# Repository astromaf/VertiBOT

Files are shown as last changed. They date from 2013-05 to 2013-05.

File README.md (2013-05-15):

VertiBOT
========

VertiBOT is an educational project to investigate and understand sensor fusion using kalman and complementary filter algorithm and PID control in an unstable system.

VertiBOT is an inverted pendulum platform that remains balanced by means of two tiny motors, located in the bottom of the structure. The battery is attached in the top of the main body, while the electronics board is located near the rotation axis.
The feedback signal is provided by an IMU 6Dof composed by an accelerometer and a gyro. One ATmega 328 microcontroller execute the main loop every 10 milliseconds. A wireless communication over bluetooth is used to tune and check the signal response in a Graphical User Interface software.

Code,parts, video, and diagrams available in: http://madebyfrutos.wordpress.com/2013/05/02/vertibot/
 
Made(by)Frutos http://madebyfrutos.wordpress.com/
  Ocero El Bierzo, Mayo'13

Based on:
- VARESANO's Free IMU library. The hard work is done. Fabio, We won't forget you! 
  http://www.varesano.net/projects/hardware/FreeIMU
- Brett Beauregard. Introducing the Pid.Good PID library and good guide http://goo.gl/QKANE
- Patrick Olsson.X-firm System Projects. Best, Balancing guide. http://www.x-firm.com/
- Jason Dorweiler http://www.jddorweiler.appspot.com/electronics.html
- Much of the code is adapted from http://www.arduino.cc/cgi-bin/yabb2/YaBB.pl?num=1284738418/all
  and http://www.kerrywong.com/2012/03/08/a-self-balancing-robot-i
- Bildr 6Dof IMu notes and library.http://bildr.org/2012/03/stable-orientation-digital-imu-6dof-arduino/
- C. J.Fisher. Using and accelerometer for inclination sensing. Analog Device. AN-1057
- Shane Colton. A Simple solution for Balance Filter. MIT. June 2007
- J.A. Shaw. PID Algorithm & Tuning Methods. Rochester,NY.
     
External specific libraries must be used with this code. All of them are open source and can be found easily in its original repositories.
Thank for the good job done with this libraries. :)
- Free IMU: http://www.varesano.net/projects/hardware/FreeIMU
- Pololu serial-Qik (motor diver): https://github.com/pololu/qik-arduino
- PID library: http://playground.arduino.cc/Code/PIDLibrary

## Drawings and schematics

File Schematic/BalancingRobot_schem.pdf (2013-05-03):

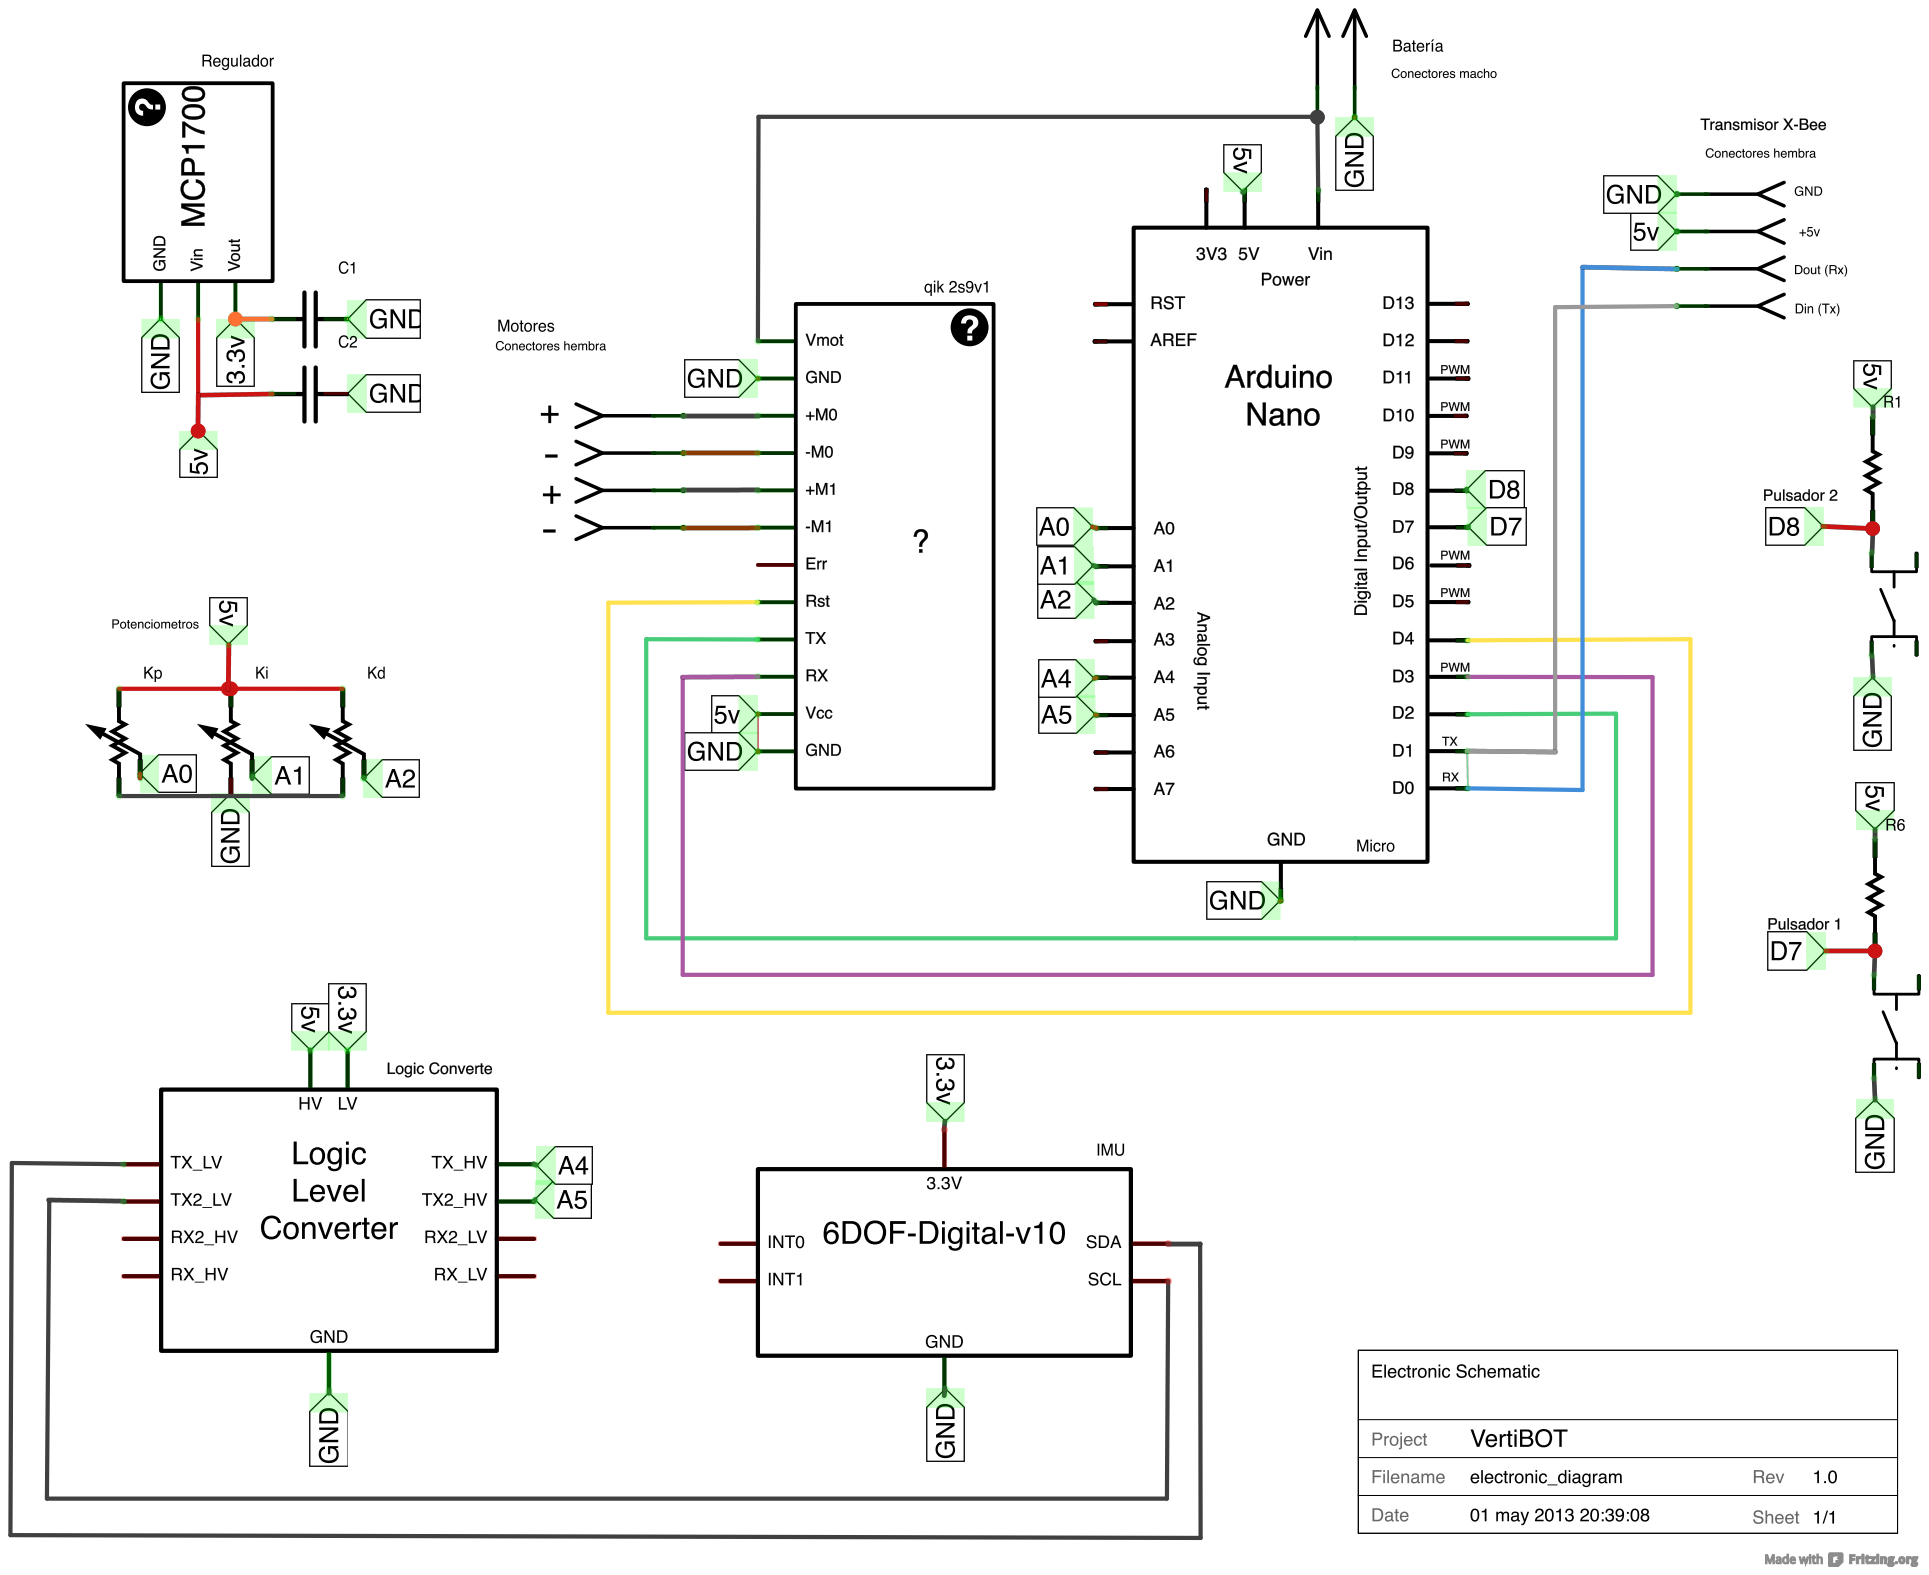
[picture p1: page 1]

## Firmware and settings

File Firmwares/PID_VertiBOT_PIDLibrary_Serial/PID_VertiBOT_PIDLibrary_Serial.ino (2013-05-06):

    /********************************************************
     // Based on:
     // VARESANO's Free IMU library. The hard work is done. Fabio, We won't forget you! http://www.varesano.net/projects/hardware/FreeIMU
     // Brett Beauregard. Introducing the Pid.Good PID library and good guide http://goo.gl/QKANE
     // Patrick Olsson.X-firm System Projects. Best, Balancing guide. http://www.x-firm.com/
     // Jason Dorweiler http://www.jddorweiler.appspot.com/electronics.html
     // Much of the code is adapted from http://www.arduino.cc/cgi-bin/yabb2/YaBB.pl?num=1284738418/all
     // and http://www.kerrywong.com/2012/03/08/a-self-balancing-robot-i
     // Bildr 6Dof IMu notes and library.http://bildr.org/2012/03/stable-orientation-digital-imu-6dof-arduino/
     // C. J.Fisher. Using and accelerometer for inclination sensing. Analog Device. AN-1057
     // Shane Colton. A Simple solution for Balance Filter. MIT. June 2007
     // J.A. Shaw. PID Algorithm & Tuning Methods. Rochester,NY.
     
     // Code,parts, video, and diagrams available in: http://madebyfrutos.wordpress.com/2013/05/02/vertibot/
 
     // Made(by)Frutos http://madebyfrutos.wordpress.com/
     // Ocero El Bierzo, Mayo'13
     
     ********************************************************/
#include <PID_v1.h>

#include <SoftwareSerial.h>
#include <PololuQik.h>

#include <FreeSixIMU.h>
#include <FIMU_ADXL345.h>
#include <FIMU_ITG3200.h>
#include <Wire.h>

//Define Variables we'll be connecting to
double Setpoint, Input, Output;

//Define the aggressive and conservative Tuning Parameters
double aggKp=66, aggKi=4, aggKd=4;
double consKp=1, consKi=0.05, consKd=0.5;

//Specify the links and initial tuning parameters
PID myPID(&Input, &Output, &Setpoint, consKp, consKi, consKd, DIRECT);

unsigned long serialTime=0; //this will help us know when to talk with processing
PololuQik2s9v1 qik(2, 3, 4);

float angles[3]; // yaw pitch roll

// Set the FreeSixIMU object
FreeSixIMU sixDOF = FreeSixIMU();
int a= 1;
int buttonState = 0;

void setup()
{
   Serial.begin(9600);
  pinMode(7, INPUT); 
  pinMode(13, OUTPUT); 
  Setpoint =89;
  qik.init();
  myPID.SetOutputLimits(-127, 127); //[-127, 127]//tell the PID to range between motor PWM response
  myPID.SetSampleTime(10);  // Ensure that the PID is called at regular interval  
  //turn the PID on
  myPID.SetMode(MANUAL);
  Wire.begin();
  
  delay(5);
  sixDOF.init(); //begin the IMU
 
}

void loop()
{
  //Input = analogRead(A0); //read angle[2]
  sensor();
 /*Change the tuning parameters: use Conservative Tuning Parameters when we're near
  setpoint and more agressive Tuning Parameters when we're farther away*/ 
   double gap = abs(Setpoint-Input); //distance away from setpoint
    if(gap<10)
    {  //we're close to setpoint, use conservative tuning parameters
      myPID.SetTunings(consKp, consKi, consKd);
    }
    else
    {
       //we're far from setpoint, use aggressive tuning parameters
       myPID.SetTunings(aggKp, aggKi, aggKd);
    }
   
  myPID.Compute();
  motores();
 // analogWrite(5,Output); //write the motor response
//Serial.println(Output);
  //send-receive with processing if it's time
  if(millis()>serialTime)
  { boton();
    ajuste();
    SerialReceive();
    SerialSend();
    serialTime+=500;
  }
  
} //END LOOP

void motores(){
  qik.setSpeeds(-Output,-Output);
  //delay(5);
}

double sensor(){
sixDOF.getEuler(angles);
Input=abs(angles[2]);

//Serial.print(Input);
//Serial.print("   ");
}

void ajuste(){
    consKp=0.007*analogRead(A2);
    consKi=0.001*analogRead(A1)+1;
    consKd=0.001*analogRead(A0);
}

void boton(){
  buttonState = digitalRead(7);
  // compare the buttonState to its previous state
  if (buttonState != 1) { 
     a=a*-1;    
    if (a==1){
      digitalWrite(13, LOW);
       myPID.SetMode(MANUAL);
       Output=0;
    }else if(a==-1){
      digitalWrite(13, HIGH);
       myPID.SetMode(AUTOMATIC);
       
    }   
  }
}

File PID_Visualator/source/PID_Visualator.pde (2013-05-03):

  /********************************************************
   // I've modified this code lightly to use with my own balancing robot. 
   // Not PID library is necesary, I'm using my own version.
   // Really nice Graphic Interface made with Processing. Nice code!
   // All the merits must go to Brett Beauregard, "the PID master" 
   
   // Code,parts,video, and diagrams for VertiBOT available in:
   // http://madebyfrutos.wordpress.com/2013/05/02/vertibot/
   
   // Made(by)Frutos http://madebyfrutos.wordpress.com/
   // Ocero El Bierzo, Mayo'13
   
   * Arduino PID Tuning Front-End,  Version 0.3
   * by Brett Beauregard
   * License: Creative-Commons Attribution Share-Alike
   * April 2011
   *
   * This application is designed to interface with an
   * arduino running the PID Library.  From this Control
   * Panel you can observe & adjust PID performance in 
   * real time
   *
   * The ControlP5 library is required to run this sketch.
   * files and install instructions can be found at
   * http://www.sojamo.de/libraries/controlP5/
   * 
   ********************************************************/
  
  import java.nio.ByteBuffer;
  import processing.serial.*;
  import controlP5.*;
  
  /***********************************************
   * User spcification section
   **********************************************/
  int windowWidth = 900;      // set the size of the 
  int windowHeight = 600;     // form
  
  float InScaleMin = 0;       // set the Y-Axis Min
  float InScaleMax = 180;    // and Max for both
  float OutScaleMin = -130;      // the top and 
  float OutScaleMax = 130;    // bottom trends
  
  
  int windowSpan = 300000;    // number of mS into the past you want to display
  int refreshRate = 100;      // how often you want the graph to be reDrawn;
  
  //float displayFactor = 1; //display Time as Milliseconds
  //float displayFactor = 1000; //display Time as Seconds
  float displayFactor = 60000; //display Time as Minutes
  
  String outputFileName = "text1.txt"; // if you'd like to output data to 
  // a file, specify the path here
  
  /***********************************************
   * end user spec
   **********************************************/
  
  int nextRefresh;
  int arrayLength = windowSpan / refreshRate+1;
  int[] InputData = new int[arrayLength];     //we might not need them this big, but
  int[] SetpointData = new int[arrayLength];  // this is worst case
  int[] OutputData = new int[arrayLength];
  
  
  float inputTop = 25;
  float inputHeight = (windowHeight-70)*2/3;
  float outputTop = inputHeight+50;
  float outputHeight = (windowHeight-70)*1/3;
  
  float ioLeft = 150, ioWidth = windowWidth-ioLeft-50;
  float ioRight = ioLeft+ioWidth;
  float pointWidth= (ioWidth)/float(arrayLength-1);
  
  int vertCount = 10;
  
  int nPoints = 0;
  
  float Input, Setpoint, Output;
  
  boolean madeContact =false;
  boolean justSent = true;
  
  Serial myPort;
  
  ControlP5 controlP5;
  controlP5.Button AMButton, DRButton;
  controlP5.Textlabel AMLabel, AMCurrent, InLabel, 
  OutLabel, SPLabel, PLabel, 
  ILabel, DLabel,DRLabel, DRCurrent;
  controlP5.Textfield SPField, InField, OutField, 
  PField, IField, DField;
  
  PrintWriter output;
  PFont AxisFont, TitleFont; 
  
  void setup()
  {
    frameRate(30);
    size(windowWidth , windowHeight);
  
    println(Serial.list());                                           // * Initialize Serial
                                                          myPort = new Serial(this, Serial.list()[8], 9600);                //   Communication with
    myPort.bufferUntil(10);                                           //   the Arduino
  
    controlP5 = new ControlP5(this);                                  // * Initialize the various
    SPField= controlP5.addTextfield("Setpoint",10,100,60,20);         //   Buttons, Labels, and
    InField = controlP5.addTextfield("Input",10,150,60,20);           //   Text Fields we'll be
    OutField = controlP5.addTextfield("Output",10,200,60,20);         //   using
    PField = controlP5.addTextfield("Kp (Proportional)",10,275,60,20);          //
    IField = controlP5.addTextfield("Ki (Integral)",10,325,60,20);          //
    DField = controlP5.addTextfield("Kd (Derivative)",10,375,60,20);          //
    AMButton = controlP5.addButton("Toggle_AM",0.0,10,50,60,20);      //
    AMLabel = controlP5.addTextlabel("AM","Manual",12,72);            //
    AMCurrent = controlP5.addTextlabel("AMCurrent","Manual",80,65);   //
    controlP5.addButton("Send new values",0.0,10,475,90,20);         //
    SPLabel=controlP5.addTextlabel("SP","3",80,103);                  //
    InLabel=controlP5.addTextlabel("In","1",80,153);                  //
    OutLabel=controlP5.addTextlabel("Out","2",80,203);                //
    PLabel=controlP5.addTextlabel("P","4",80,278);                    //
    ILabel=controlP5.addTextlabel("I","5",80,328);                    //
    DLabel=controlP5.addTextlabel("D","6",80,378);                    //
    DRButton = controlP5.addButton("Toggle_DR",0.0,10,425,60,20);      //
    DRLabel = controlP5.addTextlabel("DR","Direct",12,447);            //
    DRCurrent = controlP5.addTextlabel("DRCurrent","Direct",80,440);   //
  
    AxisFont = loadFont("axis.vlw");
    TitleFont = loadFont("Titles.vlw");
   
    nextRefresh=millis();
    if (outputFileName!="") output = createWriter(outputFileName);
  }
  
  void draw()
  {
    background(200);
    drawGraph();
    drawButtonArea();
  }
  
  void drawGraph()
  {
    //draw Base, gridlines
    stroke(0);
    fill(230);
    rect(ioLeft, inputTop,ioWidth-1 , inputHeight);
    rect(ioLeft, outputTop, ioWidth-1, outputHeight);
    stroke(210);
  
    //Section Titles
    textFont(TitleFont);
    fill(255);
    text("PID Input / Setpoint",(int)ioLeft+10,(int)inputTop-5);
    text("PID Output",(int)ioLeft+10,(int)outputTop-5);
  
  
    //GridLines and Titles
    textFont(AxisFont);
    
    //horizontal grid lines
    int interval = (int)inputHeight/5;
    for(int i=0;i<6;i++)
    {
      if(i>0&&i<5) line(ioLeft+1,inputTop+i*interval,ioRight-2,inputTop+i*interval);
      text(str((InScaleMax-InScaleMin)/5*(float)(5-i)+InScaleMin),ioRight+5,inputTop+i*interval+4);
  
    }
    interval = (int)outputHeight/5;
    for(int i=0;i<6;i++)
    {
      if(i>0&&i<5) line(ioLeft+1,outputTop+i*interval,ioRight-2,outputTop+i*interval);
      text(str((OutScaleMax-OutScaleMin)/5*(float)(5-i)+OutScaleMin),ioRight+5,outputTop+i*interval+4);
    }
  
  
    //vertical grid lines and TimeStamps
    int elapsedTime = millis();
    interval = (int)ioWidth/vertCount;
    int shift = elapsedTime*(int)ioWidth / windowSpan;
    shift %=interval;
  
    int iTimeInterval = windowSpan/vertCount;
    float firstDisplay = (float)(iTimeInterval*(elapsedTime/iTimeInterval))/displayFactor;
    float timeInterval = (float)(iTimeInterval)/displayFactor;
    for(int i=0;i<vertCount;i++)
    {
      int x = (int)ioRight-shift-2-i*interval;
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

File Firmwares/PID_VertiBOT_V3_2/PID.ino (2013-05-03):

// Patrick Olsson.X-firm System Projects. Best, Balancing guide. http://www.x-firm.com/

#define   GUARD_GAIN   100.0

float last_error = 0;
float integrated_error = 0;
float pTerm = 0, iTerm = 0, dTerm = 0;

float updatePid(float targetPosition, float currentPosition, float K, float Kp, float Ki,float Kd)   {
  error = targetPosition - currentPosition; 
  pTerm = Kp * error;
  integrated_error += error;                                       
  iTerm = Ki * constrain(integrated_error, -GUARD_GAIN, GUARD_GAIN);
  dTerm = Kd * (error - last_error);                            
  last_error = error;
  return -constrain(K*(pTerm + iTerm + dTerm), -127, 127);
}

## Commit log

2013-05-03 Code added
    [VertiBOT_ElectronicDiagram.fzz]
2013-05-06 PID library test
